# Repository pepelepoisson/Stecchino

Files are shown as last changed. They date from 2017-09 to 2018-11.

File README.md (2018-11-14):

Project logo
***
Stecchino is an home-made game where you need to balance a stick-like device at the tip of your fingers. The longer you can keep it balanced the more LEDs are lit on the Stecchino device. Can you do better than your friends?
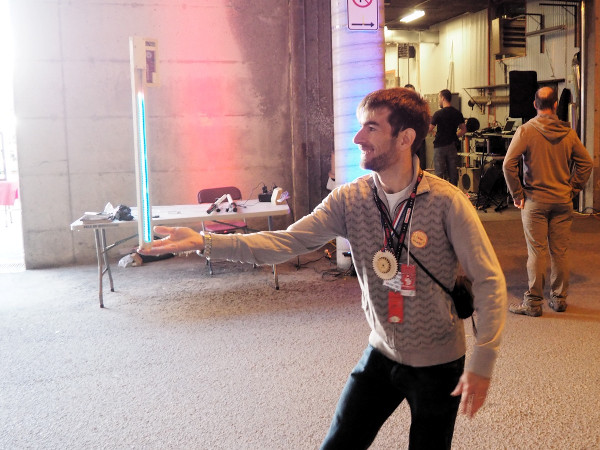
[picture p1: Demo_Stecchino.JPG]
Demo photo

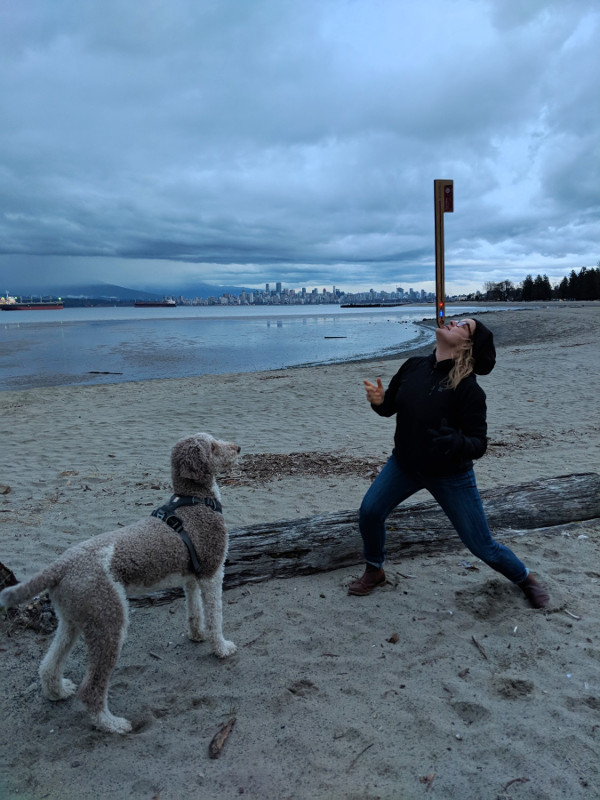
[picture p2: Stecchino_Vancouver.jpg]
Demo Vancouver

***
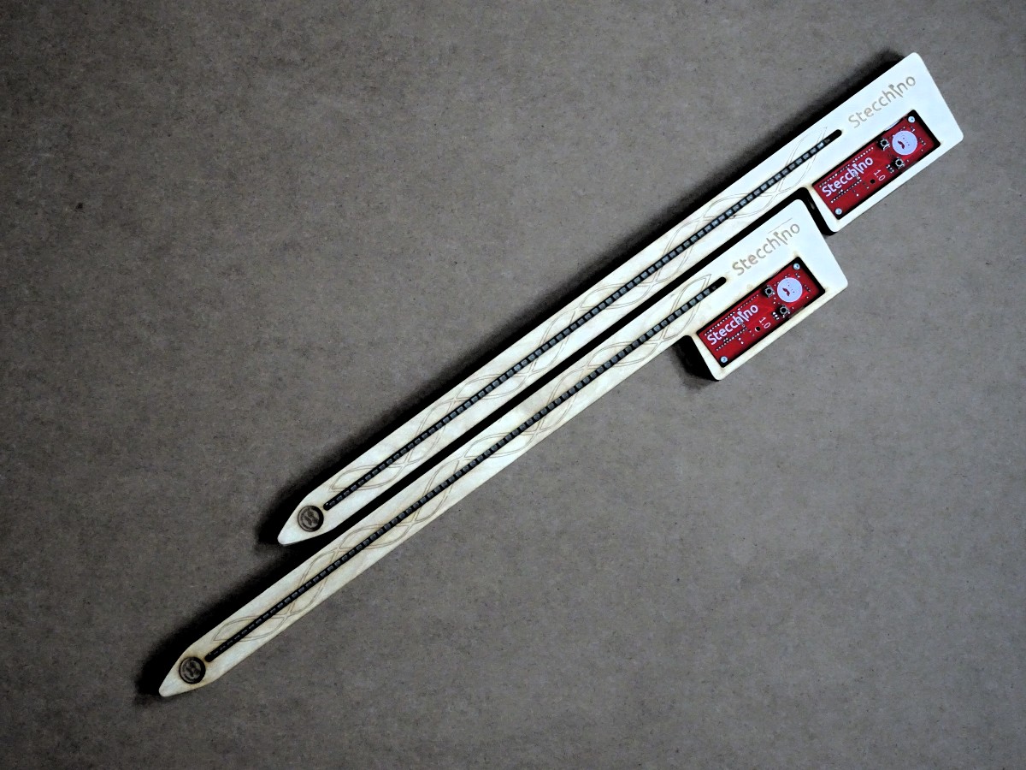
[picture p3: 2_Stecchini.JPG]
Stecchini

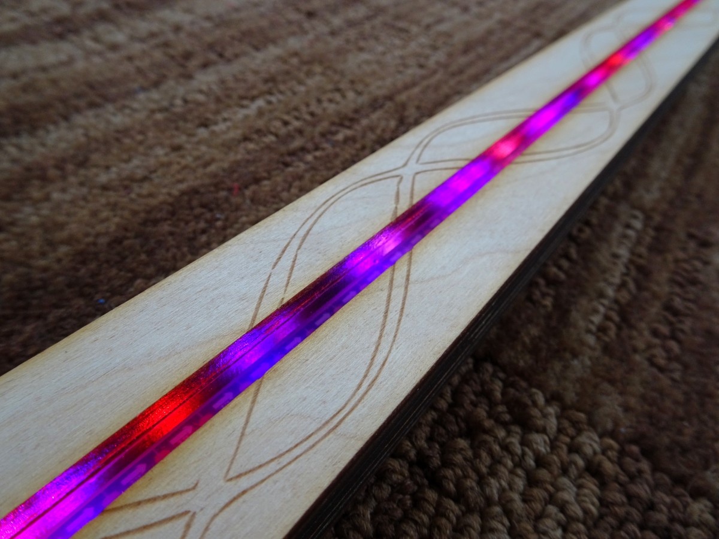
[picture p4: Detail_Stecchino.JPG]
Details

More details, photos and videos at http://www.chezpapietmamie.com/pcube/arduino/stecchino/
***
This repo contains:
- Arduino Pro Mini sketch
- Electronic schematic, V1 PCB KiCad files and Gerbers
- Laser cut Inkscape and pdf files for V4 plywood Stecchino
***
Bill Of Material and costs for PCB V1:

|Quantity|Description|Unit cost (CAD)|Cost(CAD)|Example reference|
|---|---|---|----|---|
|1|Arduino Pro Mini 3.3V 16MHz|3,11|3,11|https://fr.aliexpress.com/item/Freeshipping-1pcs-lot-Pro-Mini-328-Mini-3-3V-16M-ATMEGA328-3-3V-16MHz-for-arduino/32695657337.html|
|1|MPU6050 accelerometer board|2|2|https://fr.aliexpress.com/item/MPU-6050-3-Axis-gyroscope-acce-lerometer-module-3V-5V-compatible-For-Arduino/2035920870.html|
|1|LiPo management board|2,4|2,4|https://fr.aliexpress.com/item/5-pcs-Micro-USB-5V-1A-18650-TP4056-Lithium-Battery-Charger-Module-Charging-Board-With-Protection/32703936097.html|
|2|Small push button|0,1|0,2|https://fr.aliexpress.com/item/Promotion-Amico-100-Pcs-6x6x4-5mm-Panel-PCB-Momentary-Tactile-Tact-Push-Button-Switch-4-Pin/32563399489.html|
|2|10K resistor|0,1|0,2||
|1|IRF9540 Mosfet|0,4|0,4||
|1|NPN transistor 2N3904|0,25|0,25||
|1|1x2 90 deg pin headers|0,2|0,2||
|1|1x3 90 deg pin headers|0,2|0,2||
|1|LiPo battery|4|4|https://fr.aliexpress.com/item/5pcs-lot-Syma-X5C-X5SW-Heng-Kee-905-Cherson-CX-30-model-aircraft-Tanco-M68-3/32603900524.html|
|1|50cm 72 WS2812B LEDs strip|10,515|10,515|https://fr.aliexpress.com/item/individually-addressable-1m-4m-5m-waterproof-ip65-ip67-5050-rgb-30-60-144-led-m-5v/32773441024.html|
|1|PCB|2|2||

Total: Approx 25.5CAD for electronics + cost of woodwork.

Make one yourself and let me know!
***
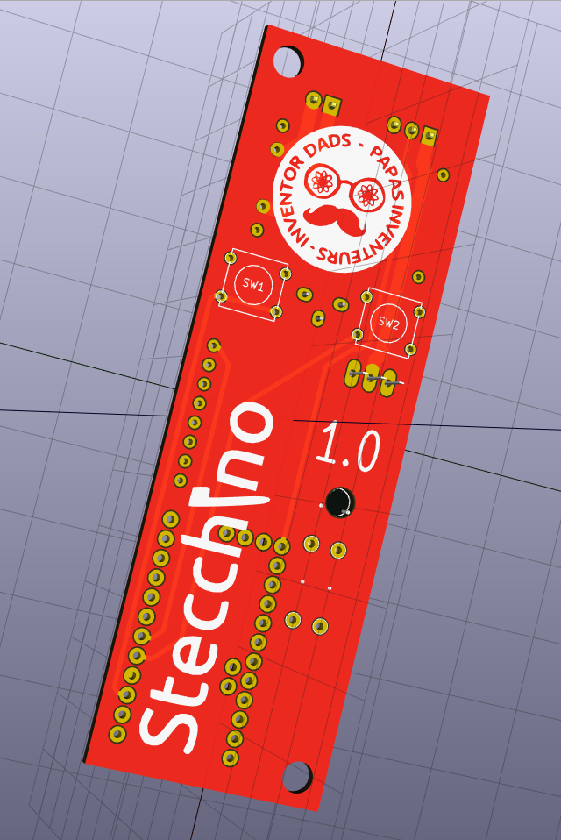
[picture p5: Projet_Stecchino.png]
PCB logo

***
A few measurements to establish minimum VCC before Stecchino starts to bug. 
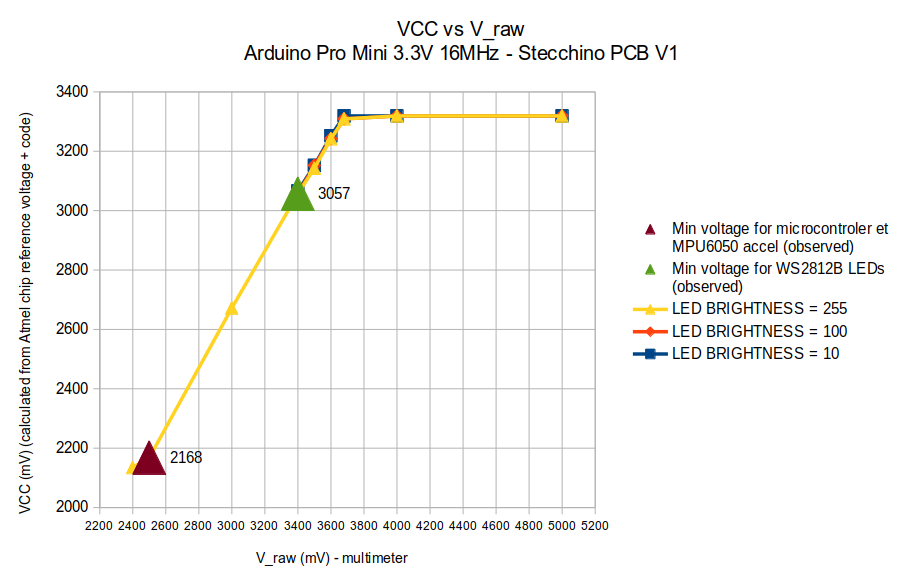
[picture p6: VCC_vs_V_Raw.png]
vcc

***
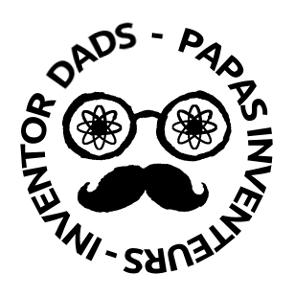
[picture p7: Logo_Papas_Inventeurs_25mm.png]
Inventor Dads logo

***
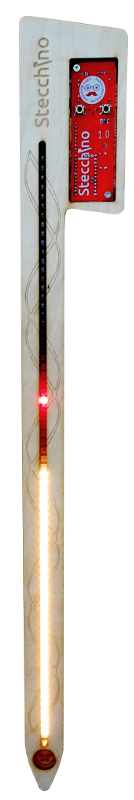
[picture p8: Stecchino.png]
Stecchino


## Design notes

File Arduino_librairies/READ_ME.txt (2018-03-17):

Copies of standard libraries used in this sketch. To be copied to arduino libraries folder.

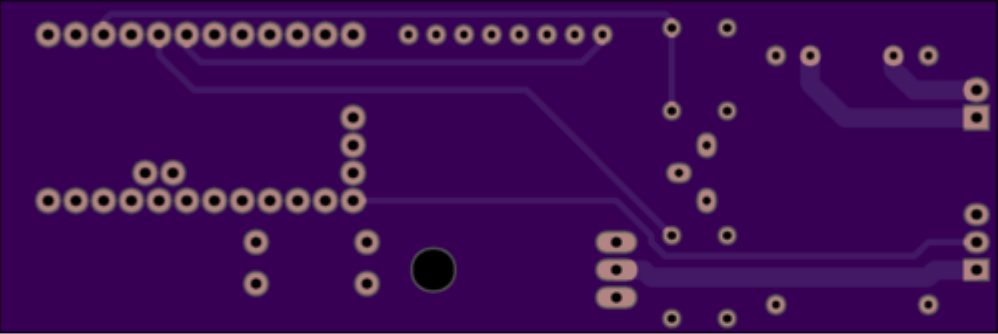
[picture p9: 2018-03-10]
Stecchino_PCB_2/images/BottomV1.png

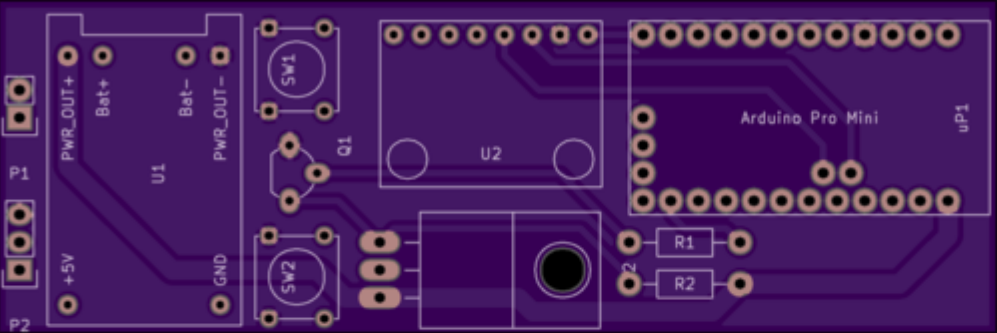
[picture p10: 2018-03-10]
Stecchino_PCB_2/images/FrontV1.png

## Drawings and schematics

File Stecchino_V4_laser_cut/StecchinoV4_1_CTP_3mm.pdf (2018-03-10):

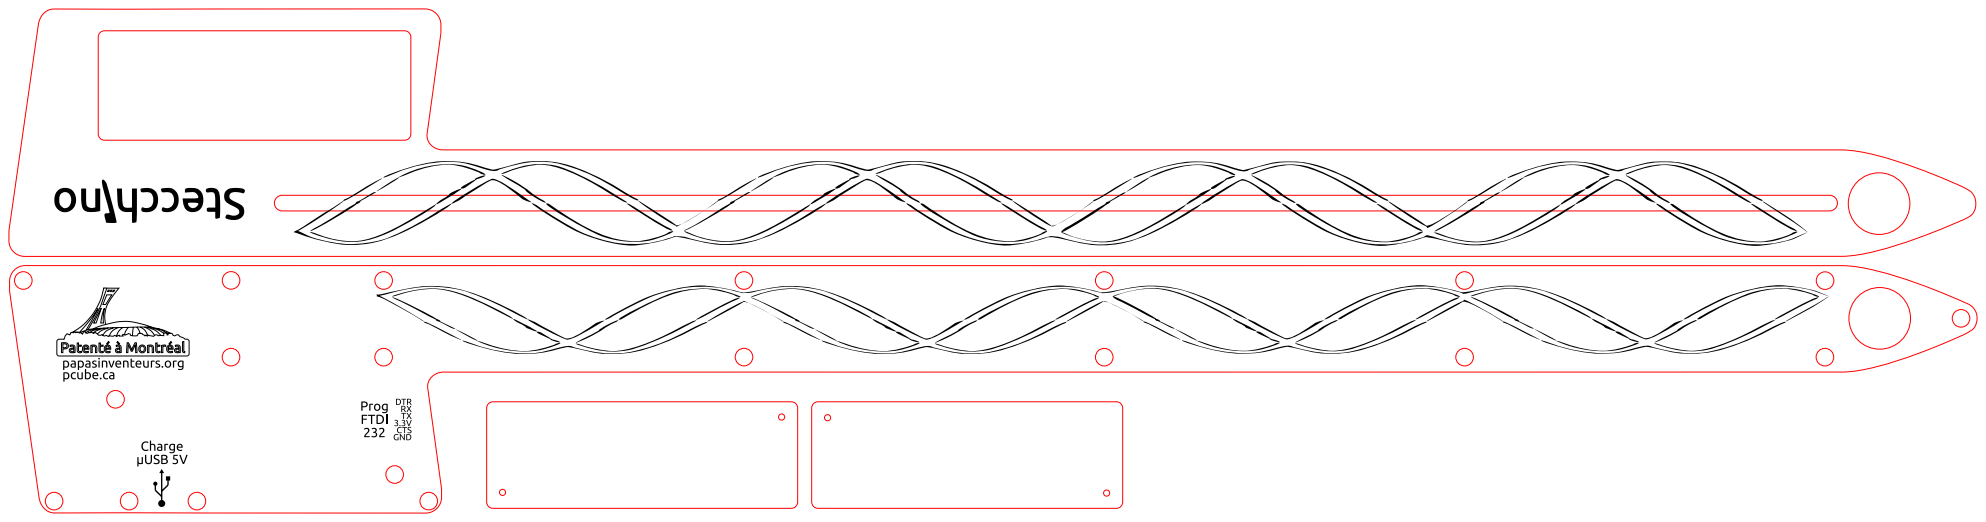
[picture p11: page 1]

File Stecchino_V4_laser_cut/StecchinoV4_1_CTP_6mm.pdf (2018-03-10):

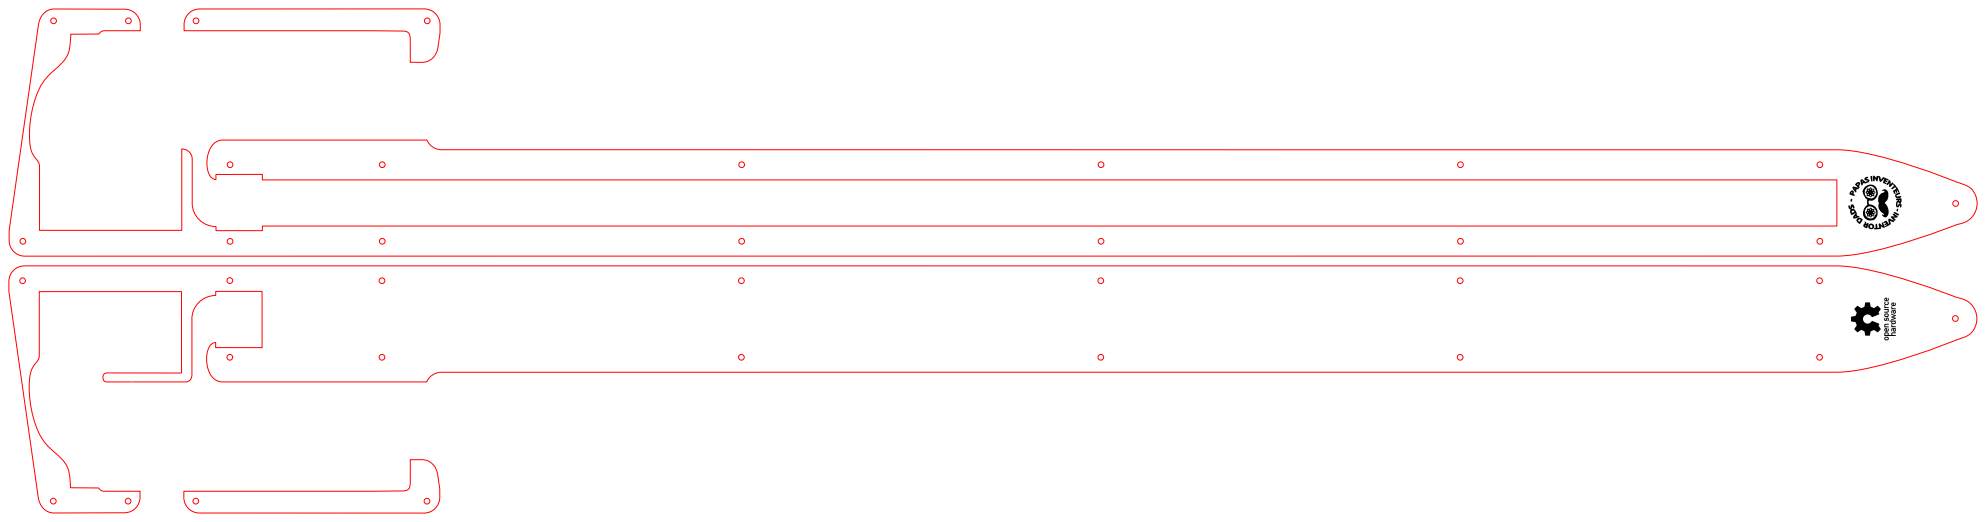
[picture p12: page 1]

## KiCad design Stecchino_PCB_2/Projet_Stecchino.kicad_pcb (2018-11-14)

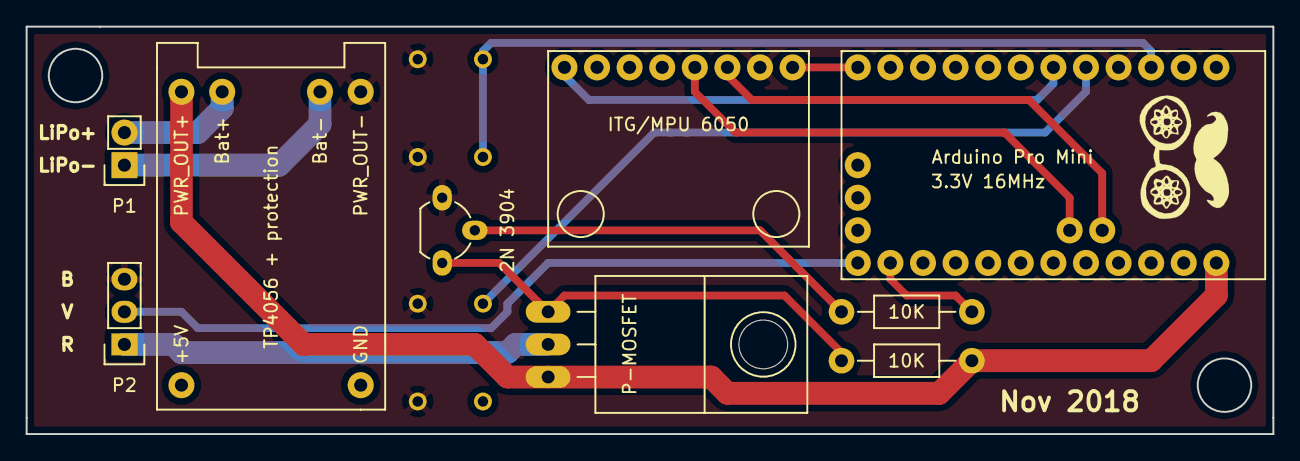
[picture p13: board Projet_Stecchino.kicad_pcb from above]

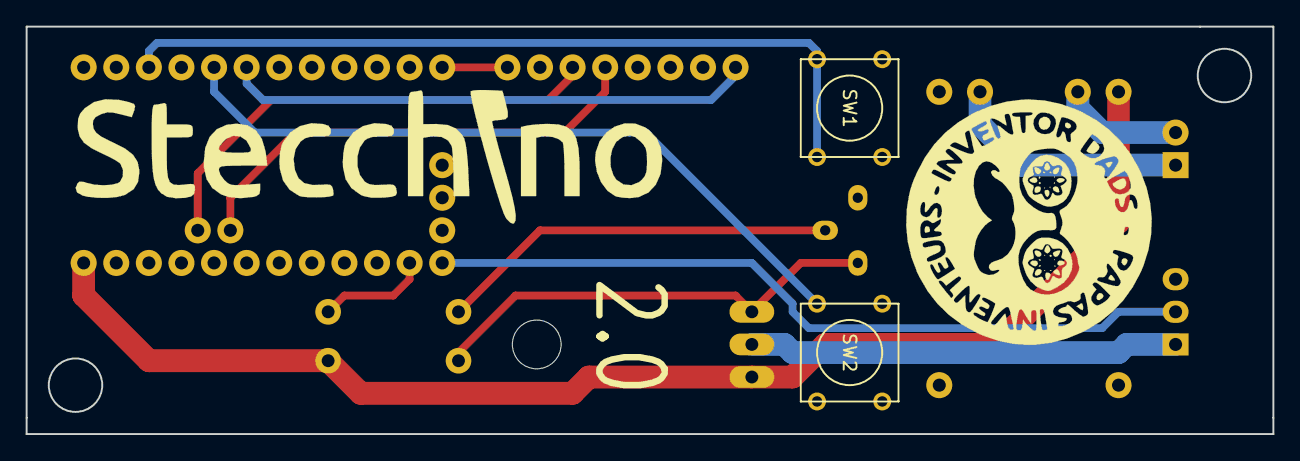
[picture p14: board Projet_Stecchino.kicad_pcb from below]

Board: 2 copper layers, 97.2 x 31.8 mm, 11 parts (2 on the bottom side), 15 nets.

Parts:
2N 3904: 2N3904; TO-92_Molded_Wide_Oval
3.3V 16MHz: ARDUPROMINI_pins_on_4_sides; ArduinoProMini_pins_on_3_sides_big_holes
10K, 10K#2: 10K; Resistor_Horizontal_RM10mm
ITG/MPU 6050: ITG/MPU6050; ITG_MPU_6050
P1: CONN_01X02; Pin_Header_Straight_1x02
P2: CONN_01X03; Pin_Header_Straight_1x03
P-MOSFET: IRF9540; TO-220_Neutral123_Horizontal_LargePads
SW1, SW2: SW_PUSH; SW_PUSH_SMALL
TP4056 + protection: LiPo_Mngmt_Board

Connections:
+BATT: 3.3V 16MHz.19, 10K#2.2, P-MOSFET.3, TP4056 + protection.4
/D2: 3.3V 16MHz.11, SW2.2
/D3: 3.3V 16MHz.12, ITG/MPU 6050.8
/I2C_SCL: 3.3V 16MHz.31, ITG/MPU 6050.3
/I2C_SDA: 3.3V 16MHz.32, ITG/MPU 6050.4
/ITG/MPU_VCC: 3.3V 16MHz.18, ITG/MPU 6050.1
/LIPO+: P1.2, TP4056 + protection.1
/LIPO-: P1.1, TP4056 + protection.2
/MOSFET_PIN: 3.3V 16MHz.29, 10K.2
/RESET: 3.3V 16MHz.9, SW1.2
/WS_DATA_IN: 3.3V 16MHz.30, P2.2
GND: 2N 3904.1, 3.3V 16MHz.10, ITG/MPU 6050.2, P2.3, SW1.1, SW2.1, TP4056 + protection.3
unnamed: P2.1, P-MOSFET.2
unnamed: 2N 3904.2, 10K.1
unnamed: 2N 3904.3, 10K#2.1, P-MOSFET.1

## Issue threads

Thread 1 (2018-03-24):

Vendor misplaced ...

RandoSY, 2018-03-24:
What a cool project!

On BOM table LED strip vendor information is missing, and in its place is info for SPST switch.

Cheers!

R.

pepelepoisson, 2018-03-24:
OK, thank you for pointing this error. I just made a correction.
Cheers.
Pascal.

pepelepoisson, 2018-03-24:
Correction made to BOM list. Thanks.

Closed 2018-03-24.

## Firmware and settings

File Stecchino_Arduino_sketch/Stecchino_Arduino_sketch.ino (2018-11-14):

// Libraries required
#include "I2Cdev.h"
#include "MPU6050.h"
#include "Wire.h"
#include "RunningMedian.h"
#include "FastLED.h" // Librarie required for addressable LEDs
#include <avr/interrupt.h> // Librairies for sleep mode
#include <avr/power.h> // Librairies for sleep mode
#include <avr/sleep.h> // Librairies for sleep mode
#include <avr/io.h> // Librairies for sleep mode

// Definitions
#define NUM_LEDS 72  // How many leds in your strip?
#define HIGH_BRIGHTNESS 50  // Set LEDS brightness
#define LOW_BRIGHTNESS 10  // Set LEDS brightness
#define DATA_PIN 10
#define MOSFET_GATE 11
#define MPU_POWER_PIN 9
#define PushB1  2 // Pin for push button 1  
#define Button_1_On  (!digitalRead(PushB1))
#define FRAMES_PER_SECOND  120
#define ARRAY_SIZE(A) (sizeof(A) / sizeof((A)[0]))
#define SET_IDLE_MILLISECONDS 20000 // how many seconds at idle before moving to Fake_sleep?
#define SET_FAKE_SLEEP_MILLISECONDS 60000 // how many seconds at Fake_sleep before moving to Sleep?
#define SET_MAX_SPIRIT_LEVEL_MILLISECONDS 20000 // how many seconds at Fake_sleep before moving to Sleep?
#define SET_MAX_PLAY_SECONDS 60 // how many milliseconds vertical before moving to Sleep? (in case Stecchino is forgotten vertical)
#define NUM_LEDS_PER_SECONDS 2 // how many LEDs are turned on every second when playing?#define WAKE_UP_TRANSITION 1000 //duration of animation when system returns from sleep (ms)
#define START_PLAY_TRANSITION 500 //duration of animation when game starts (ms)
#define GAME_OVER_TRANSITION 1000 //duration of game over animation (ms)
#define SLEEP_TRANSITION 2000 //duration of animation to sleep (ms)
#define LOW_VCC 2700  // lower vcc value when checking battery level
#define HIGH_VCC 3350  // higher vcc value when checking battery level


// Variables used in CheckAccel() routine
MPU6050 accelgyro;
int16_t ax, ay, az;
int16_t gx, gy, gz;
String accel_status=String("unknown");
RunningMedian a_forwardRollingSample = RunningMedian(5);
RunningMedian a_sidewayRollingSample = RunningMedian(5);
RunningMedian a_verticalRollingSample = RunningMedian(5);
#define ACCELEROMETER_ORIENTATION 2     // 0, 1 or 2 to set the angle of the joystick
int a_forward_offset=0,a_sideway_offset=0,a_vertical_offset=0;
enum POSITION_STECCHINO { NONE, POSITION_1,POSITION_2,POSITION_3,POSITION_4, POSITION_5, POSITION_6, COUNT };  // Used to detect position of buttons relative to Stecchino and user
const char *position_stecchino[COUNT] = { "None", "POSITION_1", "POSITION_2", "POSITION_3", "POSITION_4", "POSITION_5", "POSITION_6" };
// POSITION_1: Stecchino V3/V4 horizontal with buttons up (idle)
// POSITION_2: Stecchino V3/V4 horizontal with buttons down (force sleep)
// POSITION_3: Stecchino V3/V4 horizontal with long edge down (spirit level)
// POSITION_4: Stecchino V3/V4 horizontal with short edge down (opposite to spirit level)
// POSITION_5: Stecchino V3/V4 vertical with PCB up (normal game position = straight)
// POSITION_6: Stecchino V3/V4 vertical with PCB down (easy game position = straight)
uint8_t orientation = NONE;

unsigned long start_time=0, current_time=0, elapsed_time=0, record_time=0, previous_record_time=0;
int i=0, Vcc=0;
float angle_2_horizon=0;
bool Ready_4_Change=false;

CRGB leds[NUM_LEDS];  // Define the array of leds

//byte led_colour[NUM_LEDS];

void setup() {

  Serial.begin(9600);
  while (!Serial);

  pinMode(PushB1,INPUT);
  digitalWrite(PushB1,HIGH);  // Configure built-in pullup resitor for push button 1

  pinMode(MOSFET_GATE,OUTPUT);
  digitalWrite(MOSFET_GATE,HIGH);


  pinMode(MPU_POWER_PIN,OUTPUT);
  digitalWrite(MPU_POWER_PIN,HIGH);

  delay(500);
  
  // LEDs strip
  FastLED.addLeds<WS2812B, DATA_PIN, GRB>(leds, NUM_LEDS);  
  FastLED.setBrightness(LOW_BRIGHTNESS);  
  
  // MPU
  Wire.begin();
  accelgyro.initialize();  
  Serial.println("Starting MPU... ");
  
  //a_forward_offset=0;
  //a_sideway_offset=0;
  //a_vertical_offset=-100;

  //delay(2000);
  Vcc=int(readVcc());
  Serial.print("VCC=");
  Serial.print(Vcc);
  Serial.println("mV");
  CHECK_BATTERY_LED(Vcc);
  delay(2000);
  alloff();
  
  start_time=millis();
}

// List of patterns to cycle through.  Each is defined as a separate function below.
typedef void (*SimplePatternList[])();
SimplePatternList gPatterns = {confetti, sinelon, juggle, bpm, rainbow};
char* SimplePatternNames[]={"confetti","sinelon", "juggle", "bpm", "rainbow" };
uint8_t gCurrentPatternNumber = 0; // Index number of which pattern is current
uint8_t gHue = 0; // rotating "base color" used by many of the patterns
uint8_t gFrameCount = 0; // Inc by 1 for each Frame of Trasition, New/Changed connection(s) pattern


void LEDS_ON(int count, int record){
    for (int i = NUM_LEDS-1; i >=0; i--) {
      if (i<=NUM_LEDS-count){leds[i]=CRGB::Black;}
      //else {leds[i]=CRGB::Green;}
      else {leds[i]=CHSV(gHue, 255, 255);}
      if (i==NUM_LEDS-record){leds[i]=CRGB::Red;}
    }

  // send the 'leds' array out to the actual LED strip
  FastLED.show();  
  // insert a delay to keep the framerate modest
  FastLED.delay(1000/FRAMES_PER_SECOND);       
  // do some periodic updates
  EVERY_N_MILLISECONDS( 20 ) { gHue++; } // slowly cycle the "base color" through the rainbow
}

void LED(String pattern){
  if (pattern=="going_to_sleep"){
    digitalWrite(MOSFET_GATE,HIGH);
    FastLED.setBrightness(LOW_BRIGHTNESS); 
    for (int i = NUM_LEDS-1; i >=0; i--){
      leds[i]=CRGB::Blue;
    }
  }
  
  if (pattern=="idle"){
    digitalWrite(MOSFET_GATE,HIGH);
    FastLED.setBrightness(HIGH_BRIGHTNESS); 
    gPatterns[gCurrentPatternNumber]();
    //confetti();
    //rainbow();
  }
      
  if (pattern=="start_play"){
    digitalWrite(MOSFET_GATE,HIGH);
    FastLED.setBrightness(LOW_BRIGHTNESS); 
    for (int i = NUM_LEDS-1; i >=0; i--){
      leds[i]=CRGB::Green;
    }
  }
   
   if (pattern=="wahoo"){
    digitalWrite(MOSFET_GATE,HIGH);
    FastLED.setBrightness(HIGH_BRIGHTNESS); 
    redGlitter();
  } 
   
   if (pattern=="spirit_level"){
    digitalWrite(MOSFET_GATE,HIGH);
    FastLED.setBrightness(HIGH_BRIGHTNESS); 
    sinelon();
  } 
    
  if (pattern=="game_over"){
    digitalWrite(MOSFET_GATE,HIGH);
    FastLED.setBrightness(LOW_BRIGHTNESS); 
    for (int i = NUM_LEDS-1; i >=0; i--){
      leds[i]=CRGB::Red;
    }
  }
  
  if (pattern=="off"){
    for (int i = NUM_LEDS-1; i >=0; i--) {
      //leds[i]=CRGB::Black;
      leds[i].nscale8(230);
    }
    digitalWrite(MOSFET_GATE,LOW);
  }

  // send the 'leds' array out to the actual LED strip
  FastLED.show();  
  // insert a delay to keep the framerate modest
  FastLED.delay(1000/FRAMES_PER_SECOND);       
  // do some periodic updates
  EVERY_N_MILLISECONDS( 20 ) { gHue++; } // slowly cycle the "base color" through the rainbow
}

void SPIRIT_LEVEL_LED(float angle){
    digitalWrite(MOSFET_GATE,HIGH);
    FastLED.setBrightness(HIGH_BRIGHTNESS);
    int int_angle=int(angle);
    //int pos_led=map(int_angle,-90,90,1,NUM_LEDS);
    //int pos_led=map(int_angle,45,-45,1,NUM_LEDS);
    int pos_led=map(int_angle,-45,45,1,NUM_LEDS);
    int couleur_led=map(pos_led,0,NUM_LEDS,0,255);
    for (int i = NUM_LEDS-1; i >=0; i--){
      if (i==pos_led){leds[i]=CHSV(couleur_led, 255, 255);}
      //if (i==pos_led){leds[i]=CRGB::Blue;}
      else {leds[i]=CRGB::Black;}
    }
    // send the 'leds' array out to the actual LED strip
    FastLED.show();  
    // insert a delay to keep the framerate modest
    FastLED.delay(1000/FRAMES_PER_SECOND);  
    // do some periodic updates
  EVERY_N_MILLISECONDS( 20 ) { gHue++; } // slowly cycle the "base color" through the rainbow 
}

void CHECK_BATTERY_LED(int vcc){  // bargraph showing battery level
    digitalWrite(MOSFET_GATE,HIGH);
    FastLED.setBrightness(LOW_BRIGHTNESS);
    if (vcc<LOW_VCC){vcc=LOW_VCC;}
    if (vcc>HIGH_VCC){vcc=HIGH_VCC;}
    int pos_led=map(vcc,LOW_VCC,HIGH_VCC,1,NUM_LEDS);
    //Serial.println(vcc);
    //Serial.println(LOW_VCC);
    //Serial.println(HIGH_VCC);
    //Serial.println(pos_led);

    
    for (int i = NUM_LEDS-1; i >=0; i--){
      if (i<=pos_led){
        if (i<=5){leds[i]=CRGB::Red;}
        else if (i>5 && i<=15){leds[i]=CRGB::Orange;}
        else {leds[i]=CRGB::Green;}
        }
      else {leds[i]=CRGB::Black;}
    }
    // send the 'leds' array out to the actual LED strip
    FastLED.show();  
    // insert a delay to keep the framerate modest
    FastLED.delay(1000/FRAMES_PER_SECOND);  
    // do some periodic updates
  EVERY_N_MILLISECONDS( 20 ) { gHue++; } // slowly cycle the "base color" through the rainbow 
}

void nextPattern()
{
  // add one to the current pattern number, and wrap around at the end
  gCurrentPatternNumber = (gCurrentPatternNumber + 1) % ARRAY_SIZE( gPatterns);
}

void rainbow() 
{
  // FastLED's built-in rainbow generator
  fill_rainbow( leds, NUM_LEDS, gHue, 7);
}

void confetti() 
{
  // random colored speckles that blink in and fade smoothly
  fadeToBlackBy( leds, NUM_LEDS, 10);
  int pos = random16(NUM_LEDS);
  leds[pos] += CHSV( gHue + random8(64), 200, 255);
}

void sinelon()
{
  // a colored dot sweeping back and forth, with fading trails
  fadeToBlackBy( leds, NUM_LEDS, 20);
  int pos = beatsin16(13,0,NUM_LEDS);
  leds[pos] += CHSV( gHue, 255, 192);
}

void bpm()
{
  // colored stripes pulsing at a defined Beats-Per-Minute (BPM)
  uint8_t BeatsPerMinute = 62;
  CRGBPalette16 palette = PartyColors_p;
  uint8_t beat = beatsin8( BeatsPerMinute, 64, 255);
  for( int i = 0; i < NUM_LEDS; i++) { //9948
    leds[i] = ColorFromPalette(palette, gHue+(i*2), beat-gHue+(i*10));
  }
}

void juggle() {
  // eight colored dots, weaving in and out of sync with each other
  fadeToBlackBy( leds, NUM_LEDS, 20);
  byte dothue = 0;
  for( int i = 0; i < 8; i++) {
    leds[beatsin16(i+7,0,NUM_LEDS)] |= CHSV(dothue, 200, 255);
    dothue += 32;
  }
}

void redGlitter() {
  gFrameCount += 1;
  if (gFrameCount % 4 == 1) { // Slow down frame rate
    for ( int i = 0; i < NUM_LEDS; i++) {
      leds[i] = CHSV(HUE_RED, 0, random8() < 60 ? random8() : random8(64));
    }
  }
}
  
void alloff() {
  for (int i = NUM_LEDS-1; i >=0; i--) {
    leds[i]=CRGB::Black;
    delay(10);
    FastLED.show();
  }
  //FastLED.show();
}

enum {Check_Battery,Wake_Up_Transition,Idle,Start_Play_Transition,Play,Wahoo,Game_Over_Transition, Spirit_Level,Magic_Wand,Sleep_Transition,Fake_Sleep} condition=Idle;

void loop() {
  angle_2_horizon=CheckAccel();
  //Serial.println(condition);
  switch (condition) {

  case Check_Battery:
    Vcc=int(readVcc());
    Serial.print("VCC=");
    Serial.print(Vcc);
    Serial.println("mV");
    CHECK_BATTERY_LED(Vcc);
    delay(2000);
    alloff();
    condition=Idle;
    break;  
    
  case Wake_Up_Transition:
    break;
    
  case Idle:      
    if (Button_1_On && Ready_4_Change) { 
      //delay(20); // debouncing
      Ready_4_Change=false;
      nextPattern();  // change light patterns when button is pressed
      start_time=millis();  // restart counter to enjoy new pattern longer
    }
    if (!Button_1_On){Ready_4_Change=true;}
    if (millis()-start_time>SET_IDLE_MILLISECONDS){condition=Fake_Sleep;start_time=millis();}
    if (accel_status=="straight"){condition=Start_Play_Transition;start_time=millis();}
    if (orientation==POSITION_3){condition=Spirit_Level;start_time=millis();}
    if (orientation==POSITION_2){condition=Sleep_Transition;start_time=millis();}
    else {LED("idle");}
    break;
    
  case Start_Play_Transition:
    //if (millis()-start_time>START_PLAY_TRANSITION){condition=Play;start_time=millis();previous_record_time=record_time;}
    //else {LED("start_play");}
    alloff();
    condition=Play;
    start_time=millis();
    previous_record_time=record_time;
    break;
    
  case Play:
    elapsed_time=(millis()-start_time)/1000;
    if (elapsed_time>record_time){record_time=elapsed_time;}
    if (elapsed_time>previous_record_time && elapsed_time<=previous_record_time+1 && previous_record_time !=0){LED("wahoo");}
    if (elapsed_time>SET_MAX_PLAY_SECONDS){condition=Sleep_Transition;start_time=millis();}
    if (NUM_LEDS_PER_SECONDS*int(elapsed_time)>=NUM_LEDS){LED("wahoo");}
    else {LEDS_ON(NUM_LEDS_PER_SECONDS*int(elapsed_time),NUM_LEDS_PER_SECONDS*int(record_time));} 
    if (accel_status=="fallen"){condition=Game_Over_Transition;start_time=millis();}
    break;
    
  case Wahoo:
    break;
    
  case Game_Over_Transition:
    if (millis()-start_time>GAME_OVER_TRANSITION){condition=Idle;start_time=millis();}
    else {LED("game_over");}
    break;

  case Spirit_Level:
    if (orientation==POSITION_1 || orientation==POSITION_2){condition=Idle;start_time=millis();}
    if (millis()-start_time>SET_MAX_SPIRIT_LEVEL_MILLISECONDS){condition=Fake_Sleep;start_time=millis();}
    SPIRIT_LEVEL_LED(angle_2_horizon);
    //Serial.print("Angle to horizon:");
    //Serial.println(angle_2_horizon);
    break;
    
   case Magic_Wand:
    break;
    
   case Fake_Sleep:
    if (millis()-start_time>SET_FAKE_SLEEP_MILLISECONDS){condition=Sleep_Transition;start_time=millis();}
    if (abs(angle_2_horizon)>15){condition=Idle;start_time=millis();}
    if (Button_1_On){condition=Idle;Ready_4_Change=false;start_time=millis();}
    else LED("off");
    break; 
  
  case Sleep_Transition:
    if (millis()-start_time>SLEEP_TRANSITION){sleepNow();}
    else LED("going_to_sleep");
    break;
  }
  FastLED.show();
}

float CheckAccel(){
  // Reads acceleration from MPU6050 to evaluate current condition.
  // Tunables: 
  // Output values: accel_status=fallen or straight
  //                orientation=POSITION_1 to POSITION_6
  //                angle_2_horizon
  // Get accelerometer readings
  accelgyro.getMotion6(&ax, &ay, &az, &gx, &gy, &gz);

  float angle_2_horizon=0;

  // Offset accel readings
  //int a_forward_offset = -2;
  //int a_sideway_offset = 2;
  //int a_vertical_offset = 1;

  // Convert to expected orientation - includes unit conversion to "cents of g" for MPU range set to 2g
  int a_forward = (ACCELEROMETER_ORIENTATION == 0?ax:(ACCELEROMETER_ORIENTATION == 1?ay:az))/164;
  int a_sideway = (ACCELEROMETER_ORIENTATION == 0?ay:(ACCELEROMETER_ORIENTATION == 1?az:ax))/164;
  int a_vertical = (ACCELEROMETER_ORIENTATION == 0?az:(ACCELEROMETER_ORIENTATION == 1?ax:ay))/164;
  
  // Update rolling average for smoothing
  a_forwardRollingSample.add(a_forward);
  a_sidewayRollingSample.add(a_sideway);
  a_verticalRollingSample.add(a_vertical);

  // Get median
  int a_forwardRollingSampleMedian=a_forwardRollingSample.getMedian()-a_forward_offset;
  int a_sidewayRollingSampleMedian=a_sidewayRollingSample.getMedian()-a_sideway_offset;
  int a_verticalRollingSampleMedian=a_verticalRollingSample.getMedian()-a_vertical_offset; 
  
  // Evaluate current condition based on smoothed accelarations
  accel_status="unknown";
  if (abs(a_sidewayRollingSampleMedian)>abs(a_verticalRollingSampleMedian)||abs(a_forwardRollingSampleMedian)>abs(a_verticalRollingSampleMedian)){accel_status="fallen";}
  if (abs(a_sidewayRollingSampleMedian)<abs(a_verticalRollingSampleMedian)&&abs(a_forwardRollingSampleMedian)<abs(a_verticalRollingSampleMedian)){accel_status="straight";}
  //else {accel_status="unknown";}

  if (a_verticalRollingSampleMedian >= 80 && abs(a_forwardRollingSampleMedian) <= 25 && abs(a_sidewayRollingSampleMedian) <= 25 && orientation != POSITION_6) {
    // coté 1 en haut
    orientation = POSITION_6;
  } else if (a_forwardRollingSampleMedian >= 80 && abs(a_verticalRollingSampleMedian) <= 25 && abs(a_sidewayRollingSampleMedian) <= 25 && orientation != POSITION_2) {
    // coté 2 en haut
    orientation = POSITION_2;
  } else if (a_verticalRollingSampleMedian <= -80 && abs(a_forwardRollingSampleMedian) <= 25 && abs(a_sidewayRollingSampleMedian) <= 25 && orientation != POSITION_5) {
    // coté 3 en haut
    orientation = POSITION_5;
  } else if (a_forwardRollingSampleMedian <= -80 && abs(a_verticalRollingSampleMedian) <= 25 && abs(a_sidewayRollingSampleMedian) <= 25 && orientation != POSITION_1) {
    // coté 4 en haut
    orientation = POSITION_1;
  } else if (a_sidewayRollingSampleMedian >= 80 && abs(a_verticalRollingSampleMedian) <= 25 && abs(a_forwardRollingSampleMedian) <= 25 && orientation != POSITION_3) {
    // coté LEDs en haut
    orientation = POSITION_3;
  } else if (a_sidewayRollingSampleMedian <= -80 && abs(a_verticalRollingSampleMedian) <= 25 && abs(a_forwardRollingSampleMedian) <= 25 && orientation != POSITION_4) {
    // coté batteries en haut
    orientation = POSITION_4;
  }  else {
    // orientation = FACE_NONE;
  }

 angle_2_horizon=atan2(float(a_verticalRollingSampleMedian),float(max(abs(a_sidewayRollingSampleMedian),abs(a_forwardRollingSampleMedian))))*180/PI;

  /*
  // for debugging
  Serial.print("a_forward:");
  Serial.print(a_forwardRollingSampleMedian);
  Serial.print(" a_sideway:");
  Serial.print(a_sidewayRollingSampleMedian);
  Serial.print(" a_vertical:");
  Serial.print(a_verticalRollingSampleMedian);
  Serial.print(" - ");
  Serial.print(position_stecchino[orientation]);
  Serial.print(" - ");
  Serial.print(accel_status);
  Serial.print(" - ");
  Serial.println(angle_2_horizon);
  */
  
   return angle_2_horizon;
 }


void sleepNow(void)
{
    // Set pin 2 as interrupt and attach handler:
    attachInterrupt(0, pinInterrupt, LOW);
    delay(100);
    //
    set_sleep_mode(SLEEP_MODE_PWR_DOWN);
    //
    // Set sleep enable (SE) bit:
    sleep_enable();
    //
    // Put the device to sleep:
    digitalWrite(MOSFET_GATE,LOW);   // turn LEDs off to indicate sleep
    digitalWrite(MPU_POWER_PIN,LOW);   // turn MPU off
    sleep_mode();
    //
    // Upon waking up, sketch continues from this point.
    sleep_disable();
    digitalWrite(MOSFET_GATE,HIGH);   // turn LED on to indicate awake 
    digitalWrite(MPU_POWER_PIN,HIGH);   // turn MPU off
    delay(100);

    // clear running median buffer
    a_forwardRollingSample.clear();
    a_sidewayRollingSample.clear();
    a_verticalRollingSample.clear();
    
    // retore MPU connection
    Wire.begin();
    accelgyro.initialize();  
    Serial.println("Restarting MPU... ");
    
    condition=Check_Battery;
    start_time=millis();
}

void pinInterrupt(void)
{
    detachInterrupt(0);
}

long readVcc() {
  // Read 1.1V reference against AVcc
  // set the reference to Vcc and the measurement to the internal 1.1V reference
  #if defined(__AVR_ATmega32U4__) || defined(__AVR_ATmega1280__) || defined(__AVR_ATmega2560__)
    ADMUX = _BV(REFS0) | _BV(MUX4) | _BV(MUX3) | _BV(MUX2) | _BV(MUX1);
  #elif defined (__AVR_ATtiny24__) || defined(__AVR_ATtiny44__) || defined(__AVR_ATtiny84__)
    ADMUX = _BV(MUX5) | _BV(MUX0);
  #elif defined (__AVR_ATtiny25__) || defined(__AVR_ATtiny45__) || defined(__AVR_ATtiny85__)
    ADMUX = _BV(MUX3) | _BV(MUX2);
  #else
    ADMUX = _BV(REFS0) | _BV(MUX3) | _BV(MUX2) | _BV(MUX1);
  #endif  

  delay(2); // Wait for Vref to settle
  ADCSRA |= _BV(ADSC); // Start conversion
  while (bit_is_set(ADCSRA,ADSC)); // measuring

  uint8_t low  = ADCL; // must read ADCL first - it then locks ADCH  
  uint8_t high = ADCH; // unlocks both

  long result = (high<<8) | low;

  result = 1125300L / result; // Calculate Vcc (in mV); 1125300 = 1.1*1023*1000
  return result; // Vcc in millivolts
}

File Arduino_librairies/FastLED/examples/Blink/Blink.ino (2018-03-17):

#include "FastLED.h"

// How many leds in your strip?
#define NUM_LEDS 1

// For led chips like Neopixels, which have a data line, ground, and power, you just
// need to define DATA_PIN.  For led chipsets that are SPI based (four wires - data, clock,
// ground, and power), like the LPD8806 define both DATA_PIN and CLOCK_PIN
#define DATA_PIN 0
//#define CLOCK_PIN 13

// Define the array of leds
CRGB leds[NUM_LEDS];

void setup() { 
      // Uncomment/edit one of the following lines for your leds arrangement.
      // FastLED.addLeds<TM1803, DATA_PIN, RGB>(leds, NUM_LEDS);
      // FastLED.addLeds<TM1804, DATA_PIN, RGB>(leds, NUM_LEDS);
      // FastLED.addLeds<TM1809, DATA_PIN, RGB>(leds, NUM_LEDS);
      // FastLED.addLeds<WS2811, DATA_PIN, RGB>(leds, NUM_LEDS);
      // FastLED.addLeds<WS2812, DATA_PIN, RGB>(leds, NUM_LEDS);
      FastLED.addLeds<WS2812B, DATA_PIN, GRB>(leds, NUM_LEDS);
  	  //FastLED.addLeds<NEOPIXEL, DATA_PIN>(leds, NUM_LEDS);
      // FastLED.addLeds<APA104, DATA_PIN, RGB>(leds, NUM_LEDS);
      // FastLED.addLeds<UCS1903, DATA_PIN, RGB>(leds, NUM_LEDS);
      // FastLED.addLeds<UCS1903B, DATA_PIN, RGB>(leds, NUM_LEDS);
      // FastLED.addLeds<GW6205, DATA_PIN, RGB>(leds, NUM_LEDS);
      // FastLED.addLeds<GW6205_400, DATA_PIN, RGB>(leds, NUM_LEDS);
      
      // FastLED.addLeds<WS2801, RGB>(leds, NUM_LEDS);
      // FastLED.addLeds<SM16716, RGB>(leds, NUM_LEDS);
      // FastLED.addLeds<LPD8806, RGB>(leds, NUM_LEDS);
      // FastLED.addLeds<P9813, RGB>(leds, NUM_LEDS);
      // FastLED.addLeds<APA102, RGB>(leds, NUM_LEDS);
      // FastLED.addLeds<DOTSTAR, RGB>(leds, NUM_LEDS);

      // FastLED.addLeds<WS2801, DATA_PIN, CLOCK_PIN, RGB>(leds, NUM_LEDS);
      // FastLED.addLeds<SM16716, DATA_PIN, CLOCK_PIN, RGB>(leds, NUM_LEDS);
      // FastLED.addLeds<LPD8806, DATA_PIN, CLOCK_PIN, RGB>(leds, NUM_LEDS);
      // FastLED.addLeds<P9813, DATA_PIN, CLOCK_PIN, RGB>(leds, NUM_LEDS);
      // FastLED.addLeds<APA102, DATA_PIN, CLOCK_PIN, RGB>(leds, NUM_LEDS);
      // FastLED.addLeds<DOTSTAR, DATA_PIN, CLOCK_PIN, RGB>(leds, NUM_LEDS);
      pinMode(2, OUTPUT);
}

void loop() { 
  // Turn the LED on, then pause
  digitalWrite(2, HIGH);   // turn the LED on (HIGH is the voltage level)
  leds[0] = CRGB::Blue;
  FastLED.show();
  delay(500);
  // Now turn the LED off, then pause
  digitalWrite(2, LOW);    // turn the LED off by making the voltage LOW
  leds[0] = CRGB::Black;
  FastLED.show();
  delay(500);
}

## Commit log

2017-09-18 Added timer and ligth effects to make ganme entirely usable
2018-03-09 Added battery check routine + allowed idle pattern changes + ensure sleep after a while at idle
2018-03-10 Minor code changes + added V1.0 PCB files + V4.0 laser cut files
    [Projet_Stecchino-B.Cu.gbl, Projet_Stecchino-B.Mask.gbs, Projet_Stecchino-B.SilkS.gbo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]
2018-03-17 Added copies of Arduino librairies used + PCB V1 schematic
2018-03-24 Corrected error in LEDs strip link on BOM table
2018-11-14 Minor changes to PCB to increase hole diameters for mpu and lipo management board
    [Projet_Stecchino-B.Cu.gbl, Projet_Stecchino-B.Mask.gbs, Projet_Stecchino-B.SilkS.gbo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]
